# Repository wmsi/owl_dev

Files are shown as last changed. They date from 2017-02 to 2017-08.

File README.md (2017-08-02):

## Welcome to the WMSI Owl Kit Development repository!

Here you can find every sketch ever used on an Owl prototype, as well as some circuit diagrams and files for manufacturing. If you're brand new to the Owls, you'll probably be better off starting with our Comprehensive Owl Guide, which can be found at this link: https://goo.gl/V9kGfm

### examples/
If you are looking for example code for a specific Owl application, <b>check out the examples folder.</b> Most of the names in this folder should be self-explanatory, but if you're confused about a particular application look it up in the guide above.

The code in this folder is by far the best-commented of any in this repository, but once you work through some examples you should be able to navigate the messier prototype code without too many issues.

You can also check out [this guide](https://docs.google.com/document/d/1MRcjBNnCVSWXaH-lBgTyRSfC4LLxEa_yDphGgFJk0CI) on a basic game using the Owls.

### Fritzing/, Eagle/
In the Fritzing and Eagle folders you'll find material related to the Owl circuit as laid out for a breadboard or PCB. The Fritiing files will probably be most useful for reconstructing or understanding how all the parts of the circuit function. Use the Eagle files if you intend to manufacture a PCB or just love staring at circuit diagrams.

### owl projects/
The "owl projects" folder contains sketches for specific educational applications. Each sketch should have a long comment at the top explaining what it was built for and what it does.

### prototype code/
Only go delving into the "prototype code" folder if you have a firm grasp on all the example code. However, if you are struggling with a specific problem, there may be some code in here that solves it :)

However, you may have to peel through layers of old, uncommented, hacked together sketches.

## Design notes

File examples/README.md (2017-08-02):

NOTE: If you are looking for specific school projects such as Profile, more code for Woodland, or our Vermont Teacher workshops, jump up one level in the folder structure and click on "owl projects".

These well-commented examples are meant to serve as a jumping-off point for future Owl projects. They highligt several different directions that the Owls took over the course of development. The files are split into two main folders, for Arduino and Feather (Owl Lite and Owl) support. These folders are meant to be complementary. However, since different use cases were developed on the two different platforms they do not exactly match up. Most significantly, the Arduino folder has greater support for GPS applications since the board naturally interfaces better with GPS and LCD.

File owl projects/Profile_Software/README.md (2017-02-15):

This folder contains firmware for the Owl Prototypes used in Profile's STEAM classroom. 

For our quickstart guide visit goo.gl/jXzwo4.

To change the firmware on your Owl prototype, download this folder from the command line by using the command:

svn checkout https://github.com/wmsi/owl_dev/trunk/Profile_Software

Then you can choose a firmware version (right now only v1 and v2 are operational) and open it with the Arduino IDE. If you do not yet have the Arduino IDE on your computer, you can download it for free from https://www.arduino.cc/en/main/software. Each firmware version contains comments indicating the purpose of each variable and function. For those unfamiliar with programming microcontrollers, a good starting point may be to change the SENDDELAY constant near the top of the .ino file. This changes the wait time in between transmissions and it will be immediately obvious if your intended change took effect. Then you can move on from here to making more ambitious changes in the firmware. If you mess something up beyond repair never fear! The original firmware will remaine on github for you to download over and over again :)

Both Profile Owl Prototypes are currently loaded with profile_v2.ino. This version builds on profile_v1.ino to introduce a faster send rate and real time averaging of incoming signal strength (in receive mode). These changes are meant to help with radio direction finding (RDF) activities. For applications that focus on datalogging or sensor networks profile_v1.ino may still be a better fit. 

Do you have more questions about programming the Owls? Check out our starter guide at goo.gl/jXzwo4 or email mbucchieri@whitemountainscience.org.

Happy tinkering!

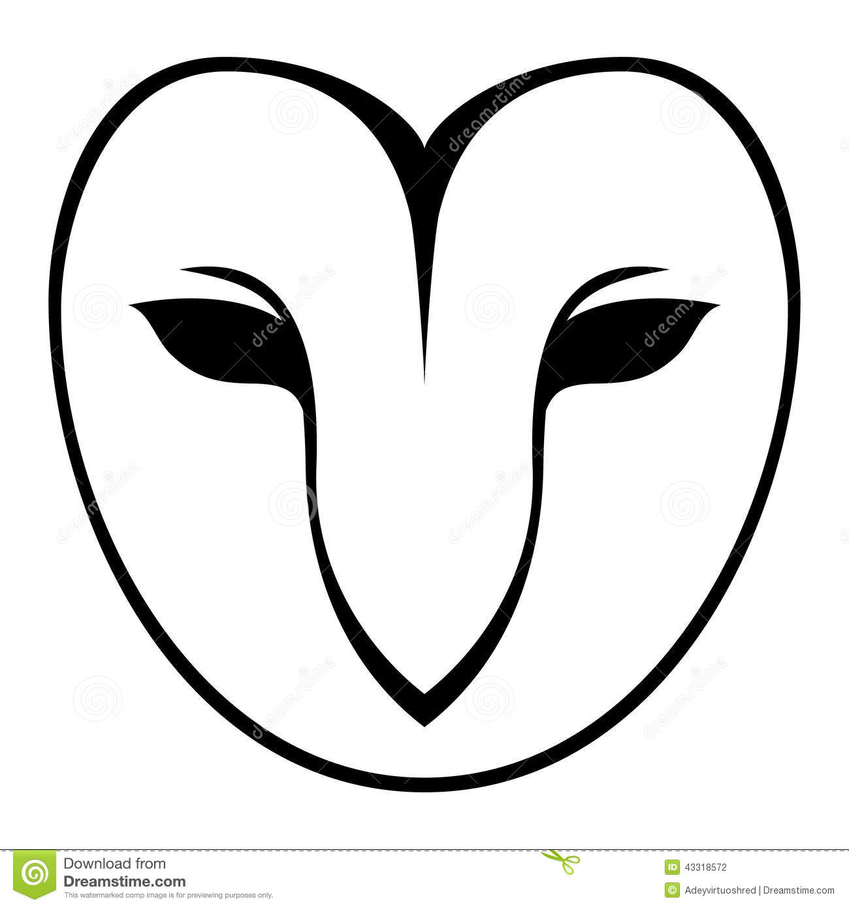
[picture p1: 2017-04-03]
owl projects/Woodland/owl-face-illustration-43318572.jpg

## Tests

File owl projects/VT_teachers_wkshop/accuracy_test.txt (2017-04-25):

LOC:44.280518,-71.691536;TIM:17:31:00;
LOC:44.280525,-71.691521;TIM:17:31:30;
LOC:44.280560,-71.691399;TIM:17:32:01;
LOC:44.280563,-71.691368;TIM:17:32:31;
LOC:44.280575,-71.691307;TIM:17:33:01;
LOC:44.280552,-71.691383;TIM:17:33:32;
LOC:44.280521,-71.691429;TIM:17:34:02;
LOC:44.280540,-71.691360;TIM:17:34:32;
LOC:44.280548,-71.691383;TIM:17:35:03;
LOC:44.280537,-71.691437;TIM:17:35:33;
LOC:44.280525,-71.691452;TIM:17:36:03;
LOC:44.280495,-71.691536;TIM:17:36:34;
LOC:44.280510,-71.691498;TIM:17:37:04;
LOC:44.280563,-71.691345;TIM:17:39:36;
LOC:44.280560,-71.691322;TIM:17:40:06;
LOC:44.280556,-71.691383;TIM:17:40:36;
LOC:44.280563,-71.691353;TIM:17:41:07;
LOC:44.280560,-71.691330;TIM:17:41:37;
LOC:44.280544,-71.691406;TIM:17:42:07;
LOC:44.280552,-71.691452;TIM:17:42:38;
LOC:44.280571,-71.691475;TIM:17:43:08;
LOC:44.280563,-71.691460;TIM:17:43:38;
LOC:44.280567,-71.691475;TIM:17:44:09;
LOC:44.280567,-71.691490;TIM:17:44:39;
LOC:44.280582,-71.691498;TIM:17:45:09;
LOC:44.280582,-71.691475;TIM:17:45:40;
LOC:44.280590,-71.691498;TIM:17:46:10;
LOC:44.280575,-71.691513;TIM:17:46:40;
LOC:44.280548,-71.691528;TIM:17:47:11;
LOC:44.280529,-71.691528;TIM:17:47:41;
LOC:44.280510,-71.691467;TIM:17:48:11;
LOC:44.280502,-71.691406;TIM:17:48:42;
LOC:44.280476,-71.691467;TIM:17:49:12;
LOC:44.280479,-71.691483;TIM:17:49:42;
LOC:44.280468,-71.691505;TIM:17:50:13;
LOC:44.280510,-71.691391;TIM:17:50:43;
LOC:44.280510,-71.691322;TIM:17:51:13;
LOC:44.280407,-71.691566;TIM:17:51:44;
LOC:44.280281,-71.691849;TIM:17:52:14;
LOC:44.280384,-71.691704;TIM:17:52:44;
LOC:44.280563,-71.691345;TIM:17:53:15;
LOC:44.280579,-71.691315;TIM:17:53:45;
LOC:44.280579,-71.691307;TIM:17:54:15;
LOC:44.280563,-71.691353;TIM:17:54:46;
LOC:44.280525,-71.691452;TIM:17:55:16;
LOC:44.280506,-71.691475;TIM:17:55:46;
LOC:44.280495,-71.691505;TIM:17:56:17;
LOC:44.280552,-71.691391;TIM:17:56:47;
LOC:44.280529,-71.691444;TIM:17:57:17;
LOC:44.280529,-71.691414;TIM:17:57:48;
LOC:44.280525,-71.691383;TIM:17:58:18;
LOC:44.280571,-71.691322;TIM:17:58:48;
LOC:44.280548,-71.691345;TIM:17:59:19;
LOC:44.280556,-71.691307;TIM:17:59:49;
LOC:44.280563,-71.691299;TIM:18:00:19;
LOC:44.280563,-71.691345;TIM:18:00:50;
LOC:44.280563,-71.691322;TIM:18:01:20;
LOC:44.280579,-71.691292;TIM:18:01:50;
LOC:44.280586,-71.691231;TIM:18:02:21;
LOC:44.280598,-71.691246;TIM:18:02:51;
LOC:44.280586,-71.691223;TIM:18:03:21;
LOC:44.280552,-71.691490;TIM:18:03:52;
LOC:44.280533,-71.691544;TIM:18:04:22;
LOC:44.280521,-71.691498;TIM:18:04:52;
LOC:44.280533,-71.691544;TIM:18:05:23;
LOC:44.280544,-71.691429;TIM:18:05:53;
LOC:44.280300,-71.691338;TIM:18:06:23;
LOC:44.280502,-71.691200;TIM:18:06:54;
LOC:44.280586,-71.691116;TIM:18:07:24;
LOC:44.280586,-71.691231;TIM:18:07:54;

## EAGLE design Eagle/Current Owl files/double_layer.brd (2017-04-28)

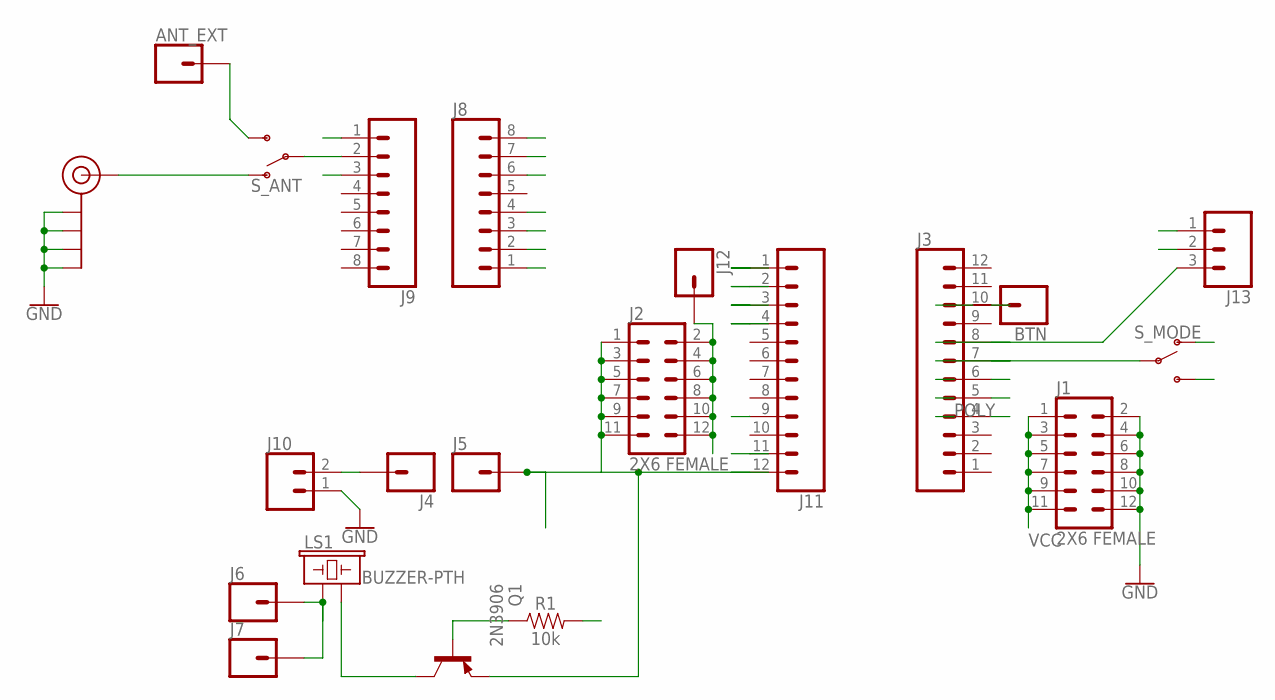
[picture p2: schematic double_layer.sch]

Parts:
ANT_EXT: CONN_01; 1X01
BTN: CONN_01; 1X01
J1, J2: 2X6 FEMALE; 2X6
J3, J11: CONN_12; 1X12
J4, J5, J6, J7, J12: CONN_01; 1X01
J8, J9: CONN_08"; 1X08
J10: CONN_02JST-PTH-2; JST-2-PTH
J13: CONN_03JST-PTH; JST-3-PTH
J$1: SMA_EDGE; SMA-EDGE
LS1: BUZZER-PTH; BUZZER-12MM
Q1: 2N3906; TO92
R1: 10k; AXIAL-0.3
S_ANT: SWITCH-SPDT-PTH-11.6X4.0MM; SWITCH_SPDT_PTH_11.6X4.0MM
S_MODE: SWITCH-SPDT-PTH-11.6X4.0MM; SWITCH_SPDT_PTH_11.6X4.0MM

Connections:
7: J3.7, S_MODE.2
8: J3.8
10: BTN.1, J3.10
ANT: J9.2, S_ANT.2
DIO0: J3.5, J8.6
GND: J1.2, J1.4, J1.6, J1.8, J1.10, J1.12, J2.2, J2.4, J2.6, J2.8, J2.10, J2.12, J3.4, J8.7, J9.1, J9.3, J10.1, J11.11, J12.1, J13.2, J$1.GND@0 (GND), J$1.GND@1 (GND), J$1.GND@2 (GND), J$1.GND@3 (GND), S_MODE.3 (S)
MISO: J8.1, J11.3
MOSI: J8.2, J11.2
unnamed: LS1.- (2), Q1.1 (C)
unnamed: Q1.2 (B), R1.P$1 (1)
unnamed: ANT_EXT.1, S_ANT.3 (S)
unnamed: J$1.SIG (SIGNAL), S_ANT.1 (O)
unnamed: J4.1, J10.2
unnamed: J6.1, J7.1, LS1.+ (1)
NSS: J8.4, J11.1
RAW: J2.1, J2.3, J2.5, J2.7, J2.9, J2.11, J5.1, J11.12, Q1.3 (E)
SCK: J8.3, J11.4
SPKR: J3.6, R1.P$2 (2)
VCC: J1.1, J1.3, J1.5, J1.7, J1.9, J1.11, J8.8, J11.9, J13.1, S_MODE.1 (O)

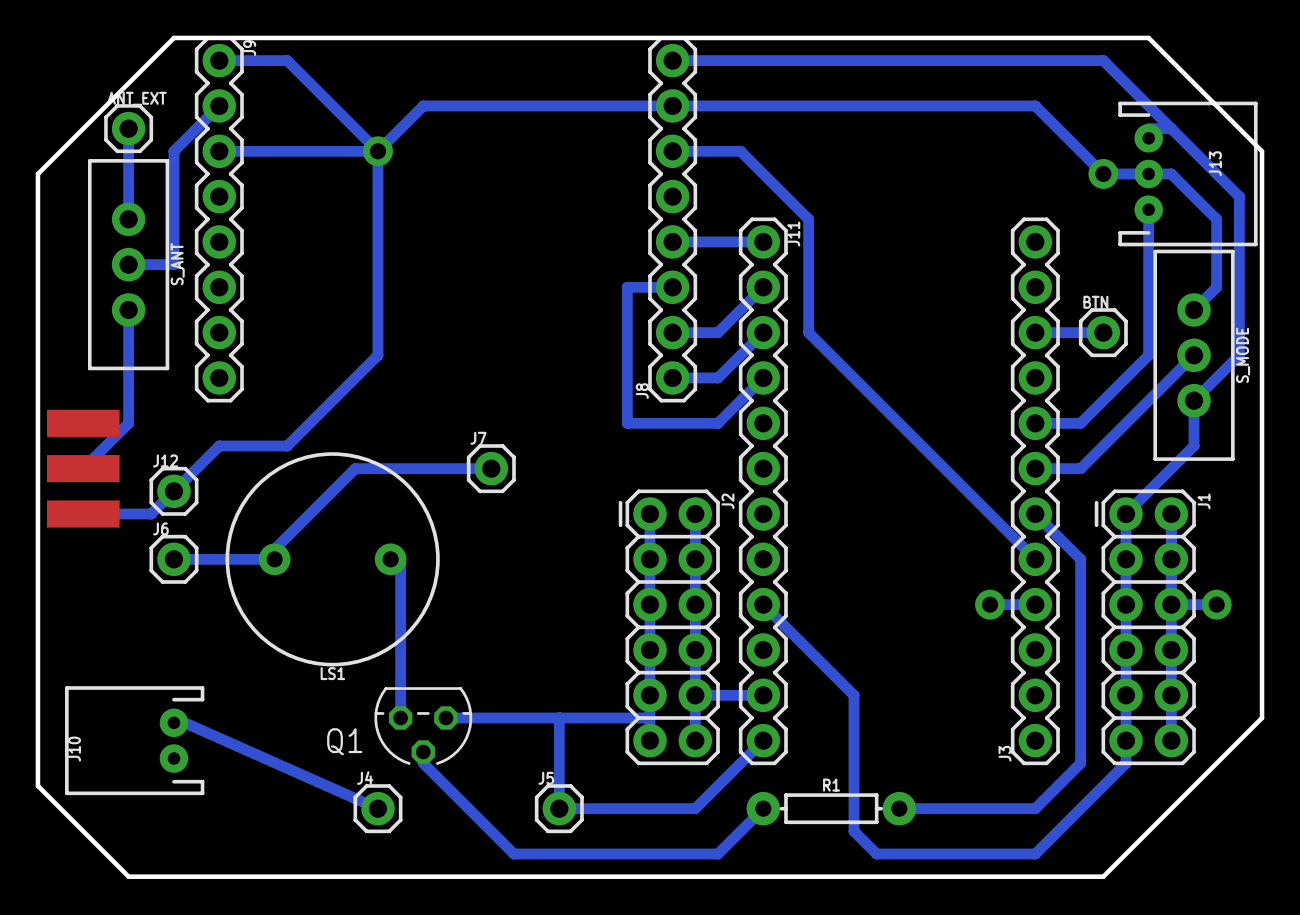
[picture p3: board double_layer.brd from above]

Board: 2 copper layers, 68.6 x 47.0 mm, 21 parts (0 on the bottom side), 18 nets.

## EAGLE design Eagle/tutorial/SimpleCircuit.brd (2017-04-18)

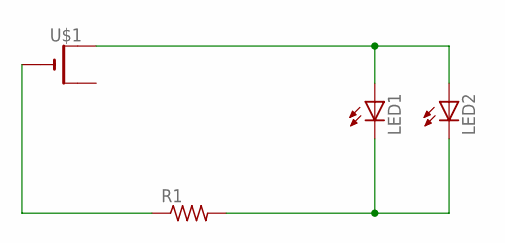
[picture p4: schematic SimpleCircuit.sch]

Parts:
LED1, LED2: LED5MM
R1: R-US_0309/12; 0309/12
U$1: CR2032THM; CR2032-THRU

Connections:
unnamed: LED1.A, LED2.A, U$1.+1 (+)
unnamed: LED1.K (C), LED2.K (C), R1.2
unnamed: R1.1, U$1.-

Board: 2 copper layers, 4 parts (0 on the bottom side), 3 nets, no tracks yet.

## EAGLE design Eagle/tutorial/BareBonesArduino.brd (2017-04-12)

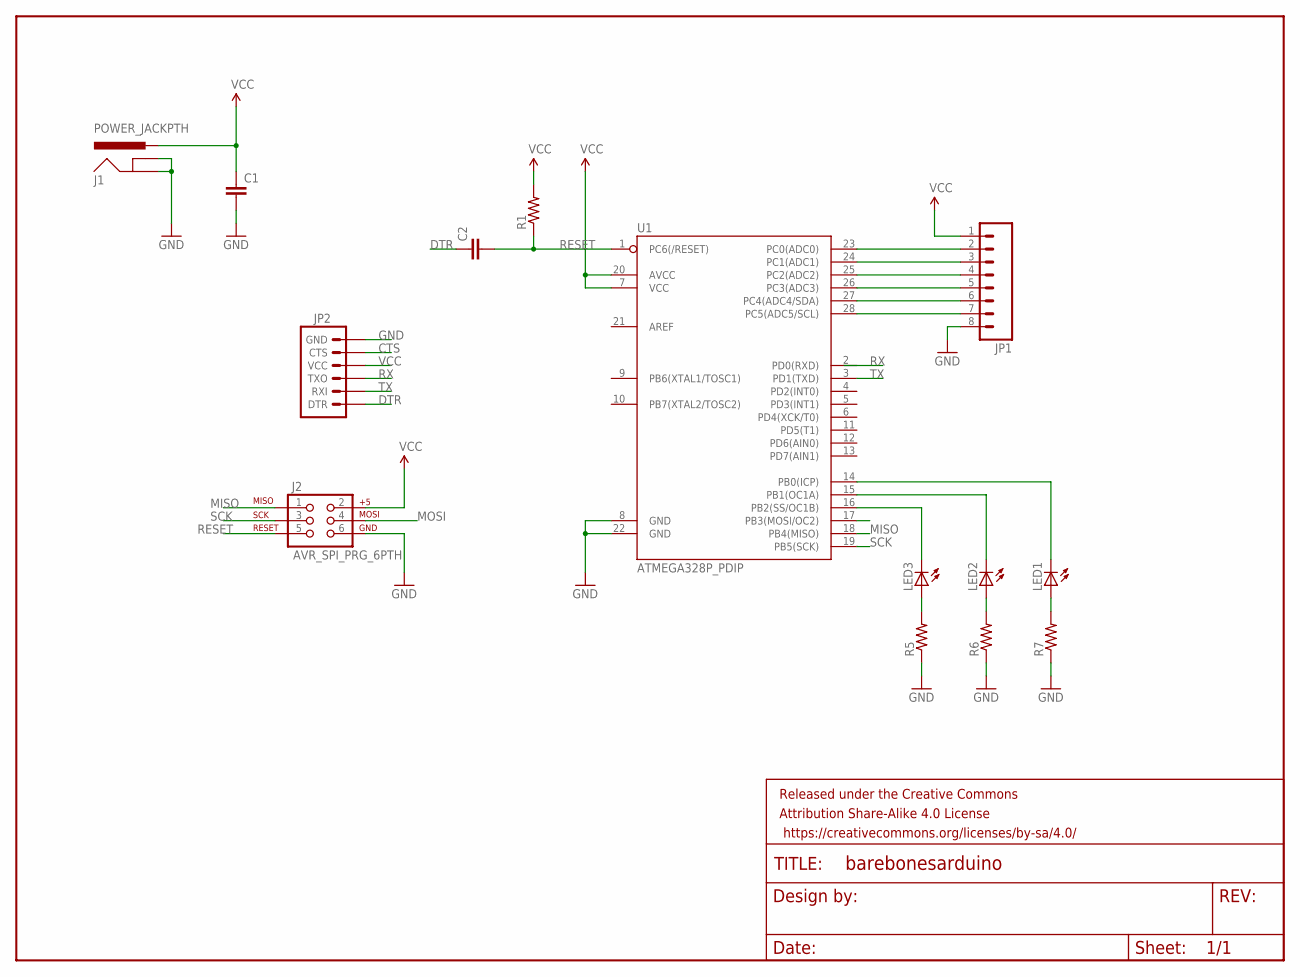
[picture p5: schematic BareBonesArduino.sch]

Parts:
C1, C2: CAPPTH; CAP-PTH-SMALL
FRAME1: FRAME-LETTER; CREATIVE_COMMONS
J1: POWER_JACKPTH; POWER_JACK_PTH
J2: AVR_SPI_PRG_6PTH; 2X3
JP1: M081X08; 1X08
JP2: ARDUINO_SERIAL_PROGRAMPTH; 1X06
LED1, LED2, LED3: LED5MM
R1, R5, R6, R7: RESISTORPTH-1/4W; AXIAL-0.4
U1: ATMEGA328P_PDIP; DIL28-3

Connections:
CTS: JP2.5 (CTS)
DTR: C2.1, JP2.1 (DTR)
GND: C1.2, J1.GND, J1.GNDBREAK, J2.6, JP1.8, JP2.6 (GND), R5.P$1 (1), R6.P$1 (1), R7.P$1 (1), U1.8 (GND), U1.22 (GND)
MISO: J2.1, U1.18 (PB4(MISO))
MOSI: J2.4, LED3.K (C), U1.16 (PB2(SS/OC1B)), U1.17 (PB3(MOSI/OC2))
unnamed: JP1.4, U1.25 (PC2(ADC2))
unnamed: LED2.A, R6.P$2 (2)
unnamed: JP1.2, U1.23 (PC0(ADC0))
unnamed: JP1.3, U1.24 (PC1(ADC1))
unnamed: JP1.5, U1.26 (PC3(ADC3))
unnamed: JP1.7, U1.28 (PC5(ADC5/SCL))
unnamed: JP1.6, U1.27 (PC4(ADC4/SDA))
unnamed: LED2.K (C), U1.15 (PB1(OC1A))
unnamed: LED1.K (C), U1.14 (PB0(ICP))
unnamed: LED3.A, R5.P$2 (2)
unnamed: LED1.A, R7.P$2 (2)
RESET: C2.2, J2.5, R1.P$1 (1), U1.1 (PC6(/RESET))
RX: JP2.3 (TXO)
SCK: J2.3, U1.19 (PB5(SCK))
TX: JP2.2 (RXI), U1.3 (PD1(TXD))
VCC: C1.1, J1.PWR, J2.2, JP1.1, JP2.4 (VCC), R1.P$2 (2), U1.7 (VCC), U1.20 (AVCC)

Board: 2 copper layers, 15 parts (0 on the bottom side), 19 nets, no tracks yet.

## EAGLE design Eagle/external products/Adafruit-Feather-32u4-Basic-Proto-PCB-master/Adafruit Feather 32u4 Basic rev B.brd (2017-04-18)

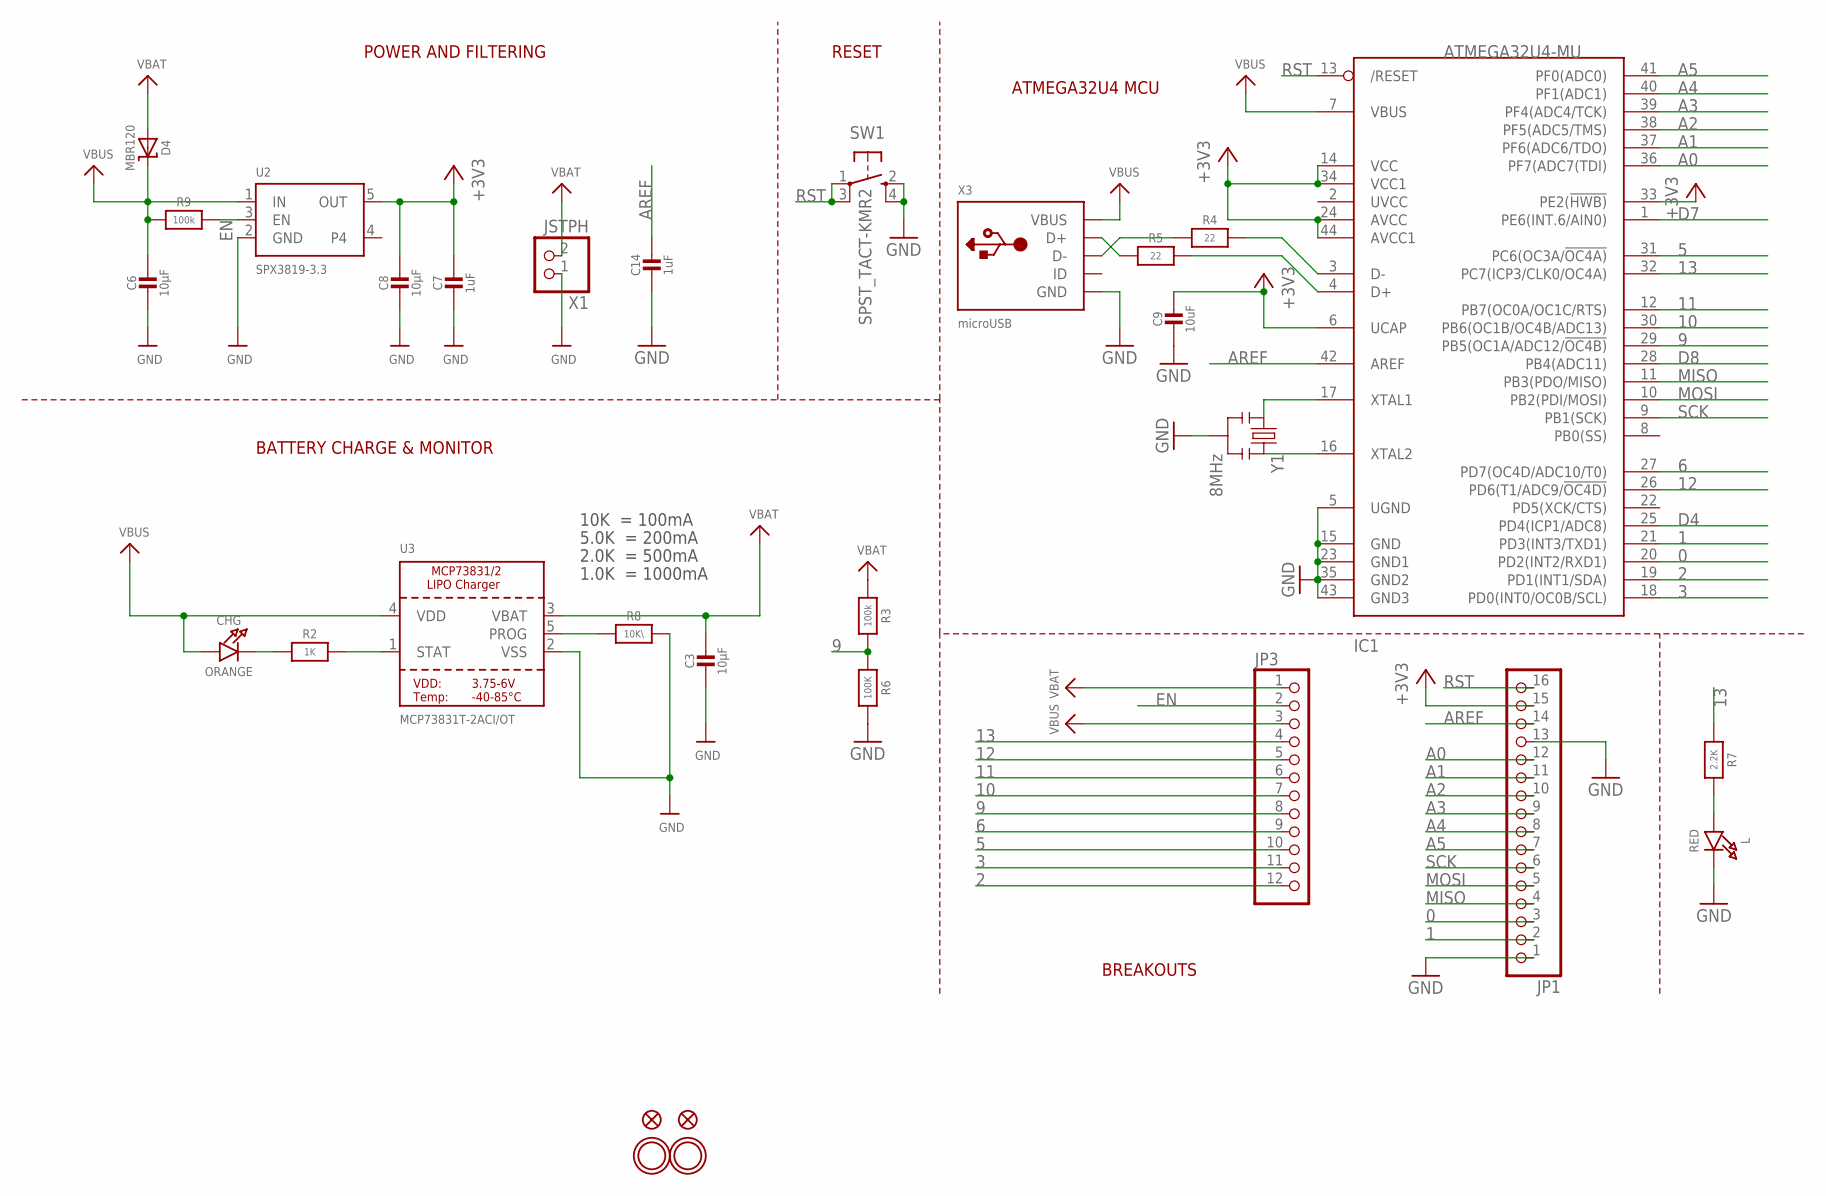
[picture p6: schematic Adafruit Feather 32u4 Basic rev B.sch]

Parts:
C3, C6, C8: 10µF; 0805-NO
C7, C14: 1uF; 0603-NO
C9: 10uF; 0805-NO
CHG: ORANGE; CHIPLED_0805_NOOUTLINE
D4: MBR120; SOD-123
IC1: ATMEGA32U4-MU; TQFN44_7MM
JP1: HEADER-1X16ROUND; 1X16_ROUND
JP3: HEADER-1X12; 1X12_ROUND
L: RED; CHIPLED_0805_NOOUTLINE
R2: 1K; 0603-NO
R3, R9: 100k; 0603-NO
R4, R5: 22; 0603-NO
R6: 100K; _0603MP
R7: 2.2K; 0603-NO
R8: 10K\; 0603-NO
SW1: SPST_TACT-KMR2; KMR2
U2: SPX3819-3.3; SOT23-5
U3: MCP73831T-2ACI/OT; SOT23-5
U$31, U$32: MOUNTINGHOLE2.5; MOUNTINGHOLE_2.5_PLATED
U$34, U$35: FIDUCIAL""; FIDUCIAL_1MM
X1: JSTPH; JSTPH2
X3: microUSB; 4UCONN_20329_V2
Y1: 8MHz; RESONATOR-SMD

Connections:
0: IC1.20 (PD2(INT2/RXD1)), JP1.3
1: IC1.21 (PD3(INT3/TXD1)), JP1.2
2: IC1.19 (PD1(INT1/SDA)), JP3.12
3: IC1.18 (PD0(INT0/OC0B/SCL)), JP3.11
5: IC1.31 (PC6(OC3A/!OC4A)), JP3.10
6: IC1.27 (PD7(OC4D/ADC10/T0)), JP3.9
9: IC1.29 (PB5(OC1A/ADC12/!OC4B)), JP3.8, R3.2, R6.1
10: IC1.30 (PB6(OC1B/OC4B/ADC13)), JP3.7
11: IC1.12 (PB7(OC0A/OC1C/RTS)), JP3.6
12: IC1.26 (PD6(T1/ADC9/!OC4D)), JP3.5
13: IC1.32 (PC7(ICP3/CLK0/OC4A)), JP3.4, R7.1
+3V3: C7.1, C8.1, C9.1, IC1.6 (UCAP), IC1.14 (VCC), IC1.24 (AVCC), IC1.33 (PE2(!HWB)), IC1.34 (VCC1), IC1.44 (AVCC1), JP1.15, U2.5 (OUT)
A0: IC1.36 (PF7(ADC7(TDI)), JP1.12
A1: IC1.37 (PF6(ADC6/TDO)), JP1.11
A2: IC1.38 (PF5(ADC5/TMS)), JP1.10
A3: IC1.39 (PF4(ADC4/TCK)), JP1.9
A4: IC1.40 (PF1(ADC1)), JP1.8
A5: IC1.41 (PF0(ADC0)), JP1.7
AREF: C14.1, IC1.42 (AREF), JP1.14
D4: IC1.25 (PD4(ICP1/ADC8))
D7: IC1.1 (PE6(INT.6/AIN0))
D8: IC1.28 (PB4(ADC11))
D+: IC1.4 (D+), R5.2
D-: IC1.3 (D-), R4.2
EN: JP3.2, R9.2, U2.3 (EN)
GND: C3.2, C6.2, C7.2, C8.2, C9.2, C14.2, IC1.5 (UGND), IC1.15 (GND), IC1.23 (GND1), IC1.35 (GND2), IC1.43 (GND3), JP1.1, JP1.13, L.C, R6.2, R8.2, SW1.2 (S), SW1.4 (S1), U2.2 (GND), U3.2 (VSS), X1.1, X3.BASE@1 (GND), X3.BASE@2 (GND), X3.GND, X3.SPRT@1 (GND), X3.SPRT@2 (GND), X3.SPRT@3 (GND), X3.SPRT@4 (GND), Y1.2
MISO: IC1.11 (PB3(PDO/MISO)), JP1.4
MOSI: IC1.10 (PB2(PDI/MOSI)), JP1.5
unnamed: CHG.C, R2.1
unnamed: L.A, R7.2
unnamed: R2.2, U3.1 (STAT)
unnamed: R8.1, U3.5 (PROG)
unnamed: IC1.16 (XTAL2), Y1.3
unnamed: IC1.17 (XTAL1), Y1.1
unnamed: R5.1, X3.D+
unnamed: R4.1, X3.D-
RST: IC1.13 (/RESET), JP1.16, SW1.1, SW1.3 (P1)
SCK: IC1.9 (PB1(SCK)), JP1.6
VBAT: C3.1, D4.A, JP3.1, R3.1, U3.3 (VBAT), X1.2
VBUS: C6.1, CHG.A, D4.C, IC1.7 (VBUS), JP3.3, R9.1, U2.1 (IN), U3.4 (VDD), X3.VBUS

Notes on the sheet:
POWER AND FILTERING
RESET
ATMEGA32U4 MCU
10K = 100mA
5.0K = 200mA
2.0K = 500mA
1.0K = 1000mA
BATTERY CHARGE & MONITOR
BREAKOUTS

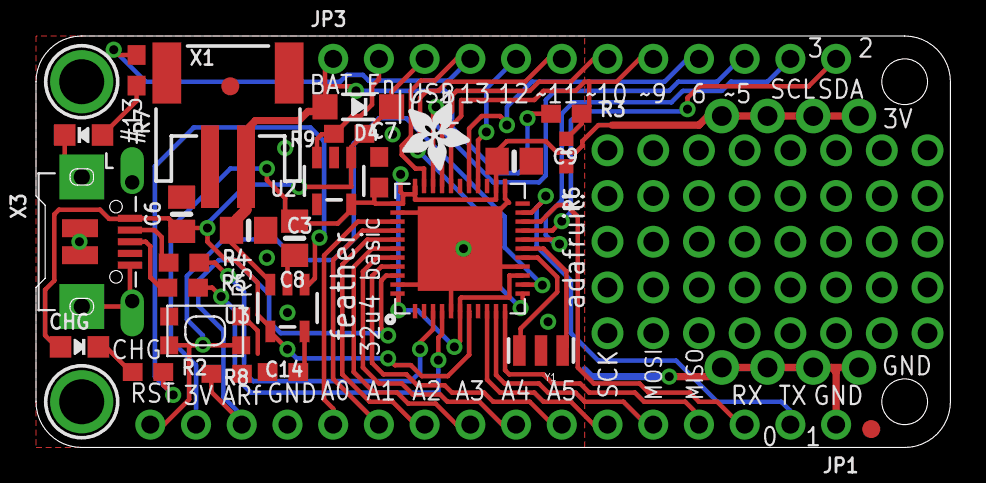
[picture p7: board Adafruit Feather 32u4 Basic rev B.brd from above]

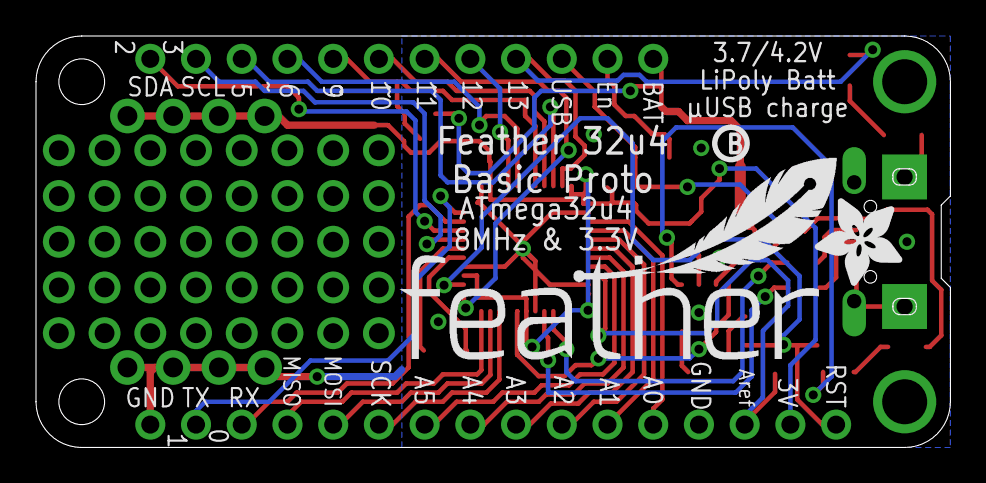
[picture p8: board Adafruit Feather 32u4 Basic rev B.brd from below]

Board: 2 copper layers, 50.8 x 22.9 mm, 34 parts (3 on the bottom side), 37 nets.

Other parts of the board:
U$4: ADAFRUIT_5MM
U$5: FEATHERLOGO
U$6: PCBFEAT-REV-040
U$7: ADAFRUIT_3.5MM

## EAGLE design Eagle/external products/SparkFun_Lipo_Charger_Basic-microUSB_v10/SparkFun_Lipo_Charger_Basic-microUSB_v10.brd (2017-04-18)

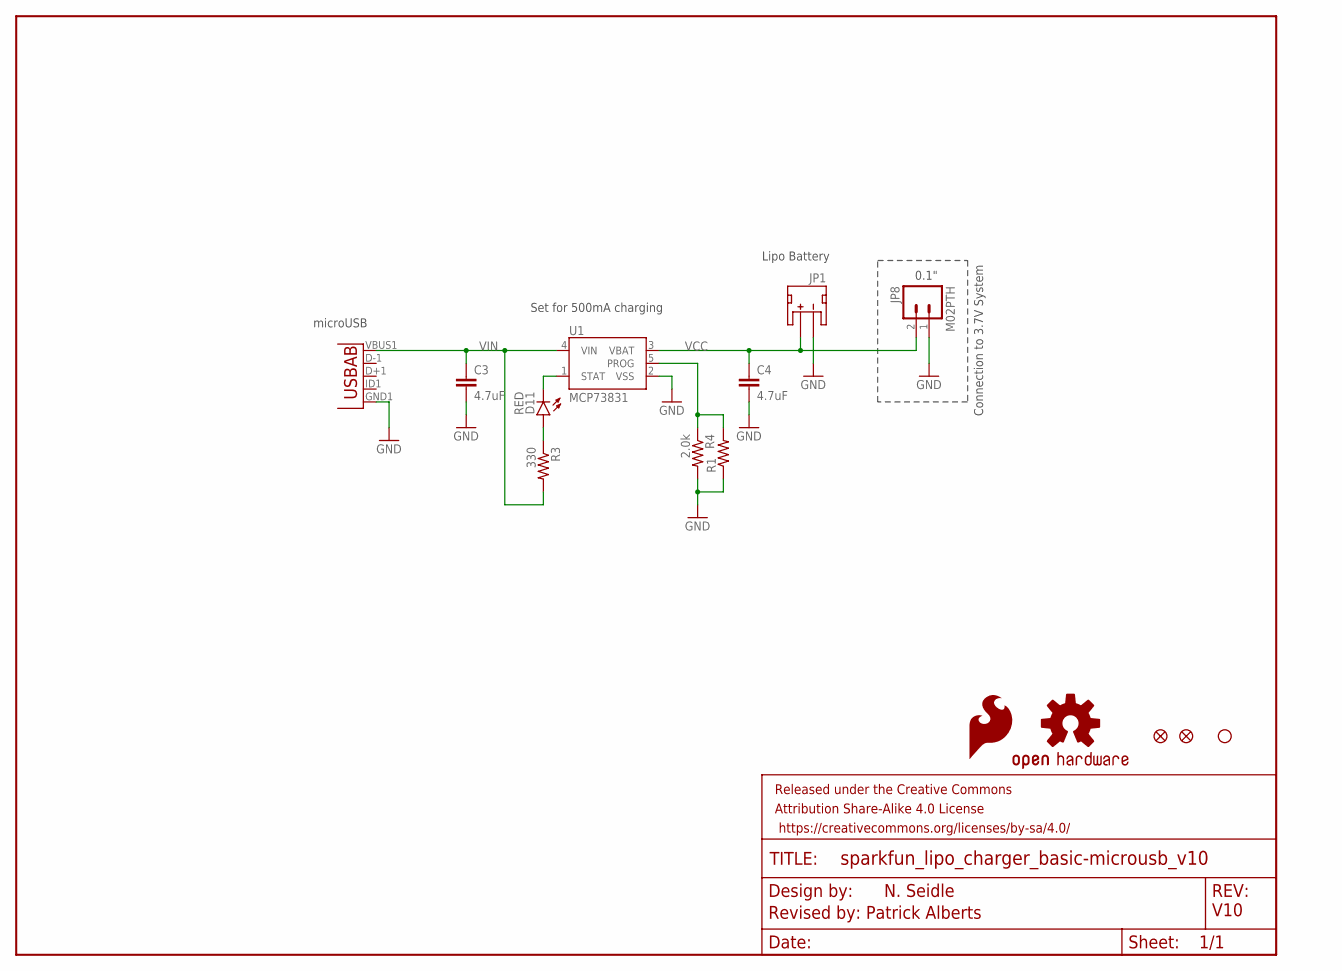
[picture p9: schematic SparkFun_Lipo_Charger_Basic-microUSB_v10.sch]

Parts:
C3, C4: 4.7uF; 0603-CAP
D11: RED; LED-0603
FRAME1: FRAME-LETTER; CREATIVE_COMMONS
JP1: JST; JST-2-SMD
JP2: STAND-OFF
JP3, JP4: FIDUCIAL1X2; FIDUCIAL-1X2
JP8: M02PTH; 1X02
JP9: Micro USB; USB-AB-MICRO-SMD_V03
LOGO1: OSHW-LOGOS; OSHW-LOGO-S
LOGO2: SFE_LOGO_FLAME.1_INCH; SFE_LOGO_FLAME_.1
R1: RESISTORPTH-1/4W-VERT-KIT; AXIAL-0.1EZ
R3: 330; 0603-RES
R4: 2.0k; 0603-RES
U1: MCP73831; SOT23-5

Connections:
GND: C3.2, C4.2, JP1.1 (-), JP8.1, JP9.GND1 (GND), R1.P$1 (1), R4.2, U1.2 (VSS)
unnamed: D11.A, R3.1
PROG: R1.P$2 (2), R4.1, U1.5 (PROG)
STAT: D11.C, U1.1 (STAT)
VCC: C4.1, JP1.2 (+), JP8.2, U1.3 (VBAT)
VIN: C3.1, JP9.VBUS1 (VBUS), R3.2, U1.4 (VIN)

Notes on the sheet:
Set for 500mA charging
Connection to 3.7V System
0.1"
N. Seidle
microUSB
Revised by: Patrick Alberts
V10
Lipo Battery

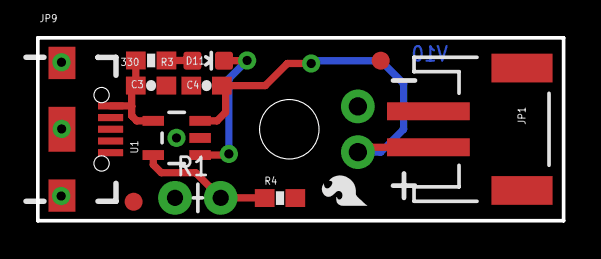
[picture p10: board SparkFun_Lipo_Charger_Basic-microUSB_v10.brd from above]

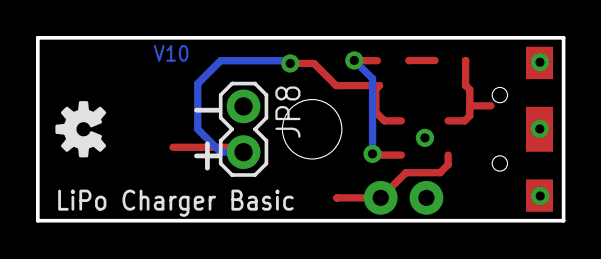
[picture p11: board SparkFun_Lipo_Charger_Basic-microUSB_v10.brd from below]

Board: 2 copper layers, 29.2 x 10.2 mm, 16 parts (2 on the bottom side), 6 nets.

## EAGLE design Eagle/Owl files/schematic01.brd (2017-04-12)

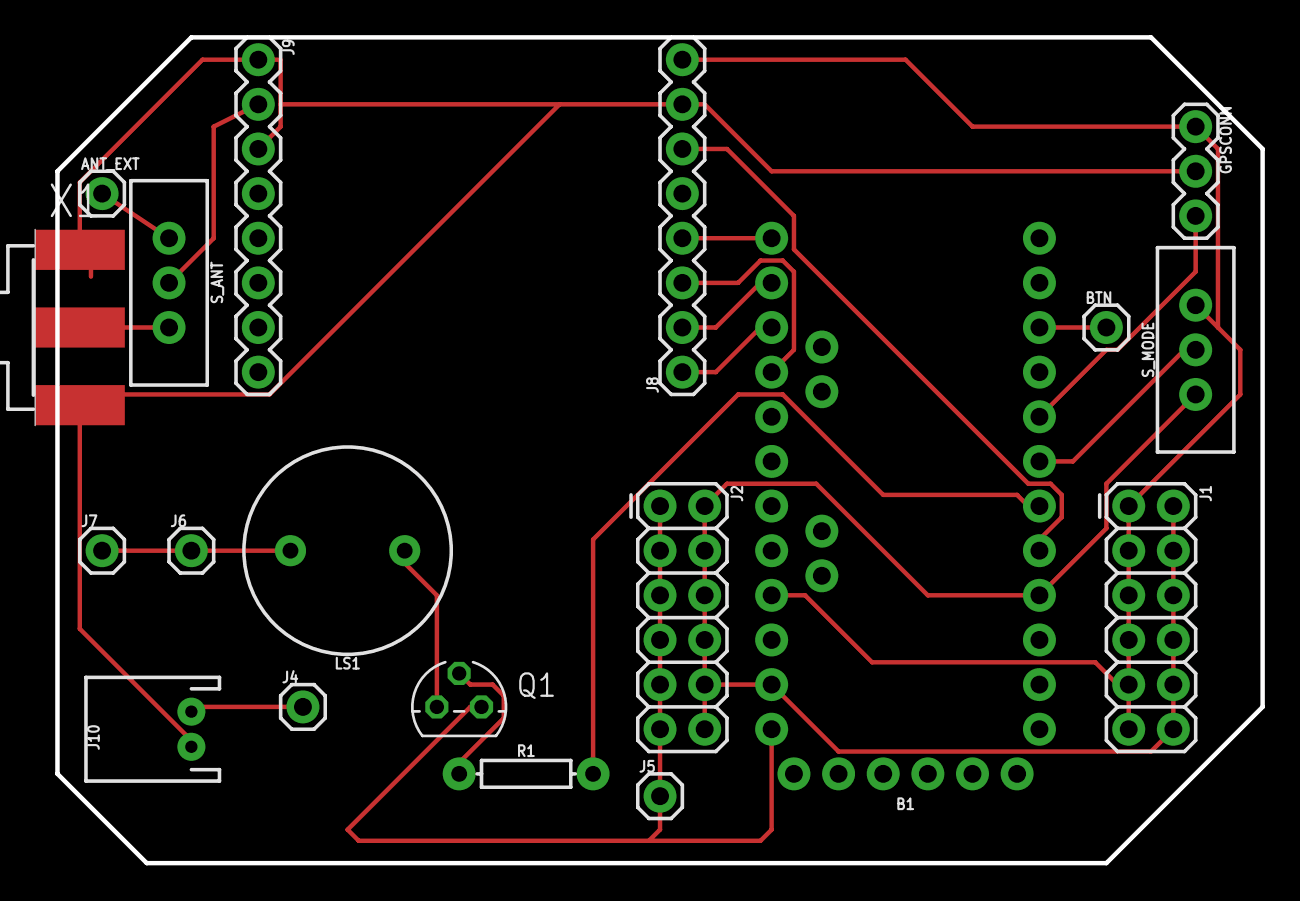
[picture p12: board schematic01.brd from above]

Board: 2 copper layers, 69.8 x 47.0 mm, 20 parts (0 on the bottom side), 19 nets.

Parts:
ANT_EXT: 1X01
B1: ARDUINO_PRO_MINI
BTN: 1X01
FRAME1: FRAME-LETTER; CREATIVE_COMMONS
GPSCONN: 1X03
J1, J2: 2X6 FEMALE; 2X6
J4, J5, J6, J7: 1X01
J8, J9: 1X08
J10: JST-2-PTH
LS1: BUZZER-PTH; BUZZER-12MM
Q1: 2N3906; TO92
R1: 10k; AXIAL-0.3
S_ANT: SWITCH_SPDT_PTH_11.6X4.0MM
S_MODE: SWITCH_SPDT_PTH_11.6X4.0MM
X1: SMA-142-0701-851/861; J502-ND-142-0701-851/861

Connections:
ANT: J9.2, S_ANT.2
DIO0: B1.5, J8.6
MISO: B1.15, J8.1
MOSI: B1.14, J8.2
unnamed: B1.8, GPSCONN.3
unnamed: B1.7, S_MODE.2
unnamed: LS1.-, Q1.3
unnamed: Q1.2, R1.P$1
unnamed: ANT_EXT.1, S_ANT.3
unnamed: S_ANT.1, X1.1
unnamed: B1.10, BTN.1
unnamed: J4.1, J10.2
unnamed: J6.1, J7.1, LS1.+
NSS: B1.13, J8.4
POLY: B1.4, B1.23, GPSCONN.2, J1.2, J1.4, J1.6, J1.8, J1.10, J1.12, J2.2, J2.4, J2.6, J2.8, J2.10, J2.12, J8.7, J9.1, J9.3, J10.1, S_MODE.3, X1.G@1, X1.G@2, X1.G@3, X1.G@4
RAW: B1.24, J2.1, J2.3, J2.5, J2.7, J2.9, J2.11, J5.1, Q1.1
SCK: B1.16, J8.3
SPKR: B1.6, R1.P$2
VCC: B1.21, GPSCONN.1, J1.1, J1.3, J1.5, J1.7, J1.9, J1.11, J8.8, S_MODE.1

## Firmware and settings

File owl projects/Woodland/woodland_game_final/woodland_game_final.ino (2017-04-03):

/*
 * This is the final draft of the Owl program for the Woodland
 * Olders' game. This sketch is intended for the units that 
 * participants will have while playing the game. It handles
 * the GPS Draw station and flippy-flop mini game.
 */

// include libraries for GPS and LCD setup
#include <TinyGPS++.h>
#include <SoftwareSerial.h>

// Include the RFM69 and SPI libraries:
#include <RFM69.h>
#include <SPI.h>

#define GPS     true
#define LCD     true
#define SERIAL  true

// Choose two Arduino pins to use for software serial
// The GPS Shield uses D2 and D3 by default when in DLINE mode
#define GPSRX 5
#define GPSTX 4
#define LCDRX 7
#define LCDTX 6

// button pin
#define BUTTON    7
#define DEBOUNCE  200

// Radio stuff
#define NETWORKID     0   // Must be the same for all nodes
static int MYNODEID;
static int TONODEID;
#define FREQUENCY     RF69_915MHZ
#define TXPOWER       31
#define ENCRYPT       false // Set to "true" to use encryption
#define ENCRYPTKEY    "TOPSECRETPASSWRD" // Use the same 16-byte key on all nodes
#define USEACK        true // Request ACKs or not

#define CENTER        512

// create a softwareSerial object to interface with the LCD
// we can use the same Rx and Tx because GPS only transmits, while LCD only receives

SoftwareSerial lcdSerial(LCDRX,LCDTX); // Rx, Tx
// Create a software serial port called "gpsSerial"
SoftwareSerial gpsSerial(GPSRX, GPSTX);

// The Skytaq EM-506 GPS module included in the GPS Shield Kit
// uses 4800 baud by default
int GPSBaud = 9600;
unsigned long dot_update = 0;
byte num_dots = 1;

// Create a TinyGPS++ object called "gps"
TinyGPSPlus gps;
double my_location[2] = {-71.768792,44.295530};
const int stage_loc[2] = {-71.748118,44.296684};
bool acquired = false;
bool new_write = true;
unsigned long last_event = 0;     // for all-purpose debouncing

const int steps[] = {2,0,1,3,4,3,5,0,1};
const int num_steps = 9;
const String key[] = {"TOP","BOTTOM","LEFT","RIGHT","FRONT","BACK"}; // {+x,-x,+y,-y,+z,-z}
int step_time = 1000;
boolean step_displayed = false;
unsigned long step_start;
int step_index = 0;
bool start_over = true;
int max_mistake_time = 1000;

RFM69 radio;

void setup() {
  // Start the Arduino hardware serial port at 9600 baud
  Serial.begin(9600);

  if(LCD)
    lcdSerial.begin(9600);
    clearLCD();
    
  // Start the software serial port at the GPS's default baud
  gpsSerial.begin(GPSBaud);

  radioSetup();

  pinMode(BUTTON, INPUT_PULLUP);
}

void loop() {
  String send_string;
  String message = "";
  if (radio.receiveDone()) {
    message = printMessage();
  }
  
  // check for GPS update
  while (gpsSerial.available() > 0) {
    if (gps.encode(gpsSerial.read())) {
      myLocation();
    }
  }

  if ((my_location[0] > -71.75 && my_location[0] < -71.745) &&
      (my_location[1] < 44.296 && my_location[1] > 44.293)) {
//if(true) {
    GPSDraw();
  } else if(runFlippyFlop()) {
    flippyFlop();
  }
  
}

//////////////        GPS-related functions         ///////////////////

void myLocation() {
  if(gps.location.isValid()) {
    acquired = true;
    my_location[0] = gps.location.lng();
    my_location[1] = gps.location.lat();
  } else if(LCD) {
    waitScreen();
  }
}

void GPSDraw() {
  String send_string;
  if(acquired) {
    if(new_write && millis() - last_event > step_time) {
      clearLCD();
      writeLine("Press button",1,2);
      writeLine("for new point",2,2);
      new_write = false;
    }
    if(digitalRead(BUTTON) == LOW && millis() - last_event > DEBOUNCE) {
      clearLCD();
      new_write = true;
      last_event = millis();
      writeLine("Sending...",1,3);
      send_string = String(String(my_location[0],5) + "," + String(my_location[1],5));
      radioSend(send_string);
    }
  }
}

int getDistance(long lat_diff, long lng_diff) {
//  Serial.print("differences: "); Serial.print(lat_diff); Serial.print(", "); Serial.println(lng_diff);
  long raw_distance = sqrt(lat_diff*lat_diff + lng_diff*lng_diff);
//  Serial.print("distance: "); Serial.println(raw_distance);
  int distance_m= raw_distance*11;
  return raw_distance;
}

//////////////         flippy flop functions        /////////////////

bool runFlippyFlop() {
  long lng_diff = my_location[0]-stage_loc[0];
  long lat_diff = my_location[1]-stage_loc[1];
  if(getDistance(lat_diff, lng_diff) < 3) {
    clearLCD();
    writeLine("Ready for your",1,1);
    writeLine("next challenge?",2,1);
  }
  unsigned long start_time = millis();
  while(millis() - start_time < 2000) {
    if(digitalRead(BUTTON) == LOW)
      return true;
  }
  return false;
}

void flippyFlop() {
  Serial.println("running flippy flop...");
  bool game_over = false;
  byte orientation;
  while(!game_over) {
    orientation = getOrientation();
//    displayStep();
    if(LCD && !step_displayed)
      writeStep();
    
    if(orientation == steps[step_index]) {
      if(step_start == 0) {
        step_start = millis();
      } else if(millis() - step_start > step_time) {
        Serial.println("got it!");
        step_index++;
        step_start = 0;
        step_displayed = false;
        if(step_index == num_steps) {
          displayDone();
          last_event = 0;
        }
      }
    } else {
      step_start = 0;
      if(step_index != 0 && orientation == steps[step_index-1]) {
        last_event = 0;
      } else if(step_index != 0 && start_over) {
        startOver();   
      }
    }
  }
}

byte getOrientation() {
  int x = analogRead(0);       // read analog input pin 0
  int y = analogRead(1);       // read analog input pin 1
  int z = analogRead(2);       // read analog input pin 2

  int up_reading;
  if(max(x,max(y,z)) - CENTER > CENTER - min(x,min(y,z))) {
    up_reading = max(x,max(y,z));
    if(x == up_reading) {
      return 1;
    } else if(y == up_reading) {
      return 3;
    } else {
      return 5;
    }
  } else {
    up_reading = min(x,min(y,z));
    if(x == up_reading) {
      return 0;
    } else if(y == up_reading) {
      return 2;
    } else {
      return 4;
    }
  }
}

String toCode(String this_step) {
  String temp = "";
  byte code;
  for(int i=0; i<this_step.length(); i++) {
    code = byte(this_step[i])-64;
    temp = String(temp + String(code));
    if(i != this_step.length()-1)
      temp = String(temp + "-");
  }
  return temp;
}

void startOver() {
  if(last_event == 0) {
    last_event = millis();
  } else if(millis() - last_event > max_mistake_time) {
    clearLCD();
    writeLine("Start Over :(",1,2);
    step_index = 0;
    step_displayed = false;
    delay(1500);
    last_event = 0;
  }
}

void writeStep() {
  clearLCD();
//  char temp[16];
  String current_step = toCode(key[steps[step_index]]);
  if(current_step.length() >= 16) {
    String part1 = current_step.substring(0,14);
    String part2 = current_step.substring(14);
    writeLine(part1,1,0);
    writeLine(part2,2,0);
  } else {
    writeLine(current_step,1,0);
  }
  step_displayed = true;
}

void welcomeScreen() {
  clearLCD();
  writeLine("Welcome to",1,3);
  writeLine("Flippy Flop!",2,2);
}

void displayDone() {
  Serial.println("you win!");
  if(LCD) {
    clearLCD();
    writeLine("You Win!",1,4);
    writeLine("Next Number: 9",2,0);
  }
  while(1);
}

//////////////               LCD functions            ///////////////

void waitScreen() {
  if(millis() - dot_update > 1000) {
    num_dots++;
    dot_update = millis();
    if(num_dots == 4)
      num_dots = 1;
  }
  String status = "Acquiring";
  for(int i=0; i<num_dots; i++) {
    status = String(status + ".");
  }
  writeLine(status,1,0);
}

void writeLine(String str, int line, int pos) {
  char temp[16] = "               ";
  int num_chars = str.length();
  lcdSerial.write(254); // move cursor to beginning of first line
  switch(line) {
    case 2:
      lcdSerial.write(191+pos);
    case 1:
      lcdSerial.write(128+pos);
  }
  delay(10);
  for(int i=0; i<num_chars; i++) {
    temp[i] = str[i];
  }
  lcdSerial.write(temp);
}

void clearLCD() {
  lcdSerial.write(254); // move cursor to beginning of first line
  lcdSerial.write(128);

  lcdSerial.write("                "); // clear display
  lcdSerial.write("                ");
}

//////////////               radio functions            ///////////////

void radioSetup() {
  MYNODEID = 1;
  TONODEID = 2;
  
  // Initialize radio
  radio.initialize(FREQUENCY,MYNODEID,NETWORKID);
  radio.setHighPower();    // Only for RFM69HCW & HW!
  radio.setPowerLevel(TXPOWER); // power output ranges from 0 (5dBm) to 31 (20dBm)
  
  // promiscuous mode allows this unit to receive all transmissions on the network
  radio.promiscuous();
  radio.encrypt(ENCRYPTKEY);

}

boolean radioSend(String send_string) {
  boolean ack_recd = false;
  byte send_length = send_string.length();
  static char send_buffer[62];
  for (byte i = 0; i < send_length; i++) {
    send_buffer[i] = send_string[i];
  }

  // There are two ways to send packets. If you want
  // acknowledgements, use sendWithRetry():
  if (USEACK) {
    if (radio.sendWithRetry(TONODEID, send_buffer, send_length, 1)) {
      ack_recd = true;
    }
  } else {
    radio.send(TONODEID, send_buffer, send_length);
  } 
  return ack_recd;
}

String printMessage() {
  char message[radio.DATALEN + 1];
  
  for (byte i = 0; i < radio.DATALEN; i++) {
    message[i] = (char)radio.DATA[i];
  }
  message[radio.DATALEN] = '\0';
  if (radio.ACKRequested()) {
    radio.sendACK();
  }

  return message;
}

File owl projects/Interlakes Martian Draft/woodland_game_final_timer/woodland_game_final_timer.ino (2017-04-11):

/* This software is intended to be run as an eample Owl activity for the 
 *  Woodland school. When powered on, each Owl will start up as either a
 *  transmitter or receiver, depending on the Mode Select switch. In 
 *  receive mode, the Owl searches for waypoints and releases a new compass 
 *  (pointing toward the transmitter) at each waypoint. The transmitter sits
 *  in a central location, broadcasting updates as the timer runs down. When 
 *  found, a button press on the transmitter will notify all receivers that it 
 *  has been retrieved.
 * 
 */

// include libraries for GPS and LCD setup
#include <TinyGPS++.h>
#include <SoftwareSerial.h>

// Include the RFM69 and SPI libraries:
#include <RFM69.h>
#include <SPI.h>

#define LCD     false
#define GPS     false
#define SERIAL  true

// Choose two Arduino pins to use for software serial
// The GPS Shield uses D2 and D3 by default when in DLINE mode
#define GPSRX 5
#define GPSTX 4
#define LCDRX 7
#define LCDTX 6

// create a softwareSerial object to interface with the LCD
// we can use the same Rx and Tx because GPS only transmits, while LCD only receives

// mode select switch
#define MODESELECT    4
#define TRANSMIT      0
#define RECEIVE       1
static bool mode;

// push to beep
#define BLUEWIRE    7
#define REDWIRE     6
#define LOOP        true

const int allotted_time = 25; //minutes
const int broadcast_interval = 540; //seconds
const int s7sTx = 8;
const int s7sRx = 7;
SoftwareSerial s7s(s7sRx, s7sTx);
unsigned long last_update = 0;
unsigned long last_broadcstopast = 0;
boolean flash_state = false;
boolean stop_display = false;
unsigned int stop_time = 0;

#define NETWORKID     0   // Must be the same for all nodes
//#define MYNODEID      1   // My node ID
//#define TONODEID      2   // Destination node ID
static int MYNODEID;
static int TONODEID;

#define FREQUENCY     RF69_915MHZ

// Transmission power (0-31 = 5-20 dBm)
#define TXPOWER       31

// AES encryption (or not):
#define ENCRYPT       false // Set to "true" to use encryption
#define ENCRYPTKEY    "TOPSECRETPASSWRD" // Use the same 16-byte key on all nodes

// Use ACKnowledge when sending messages (or not):
#define USEACK        true // Request ACKs or not

RFM69 radio;

void setup() {
  // Start the Arduino hardware serial port at 9600 baud
  Serial.begin(9600);
  
  s7s.begin(9600);

  clearDisplay();

  pinMode(MODESELECT, INPUT);
  pinMode(BLUEWIRE, INPUT_PULLUP);
  pinMode(REDWIRE, INPUT_PULLUP);

  radioSetup();
}

void loop() {
  String send_string;
  String message = "";
  if (radio.receiveDone()) {
    message = printMessage();
  }
  // update countdown timer
  updateDisplay();

  // broadcast time update
  if((millis()-last_broadcast)/1000 >= broadcast_interval) {
    Serial.println("time udpate");
    broadcastTime();
  }

  if(digitalRead(BLUEWIRE)) {
    radioSend("owl found");
    stop_display = true;
  }
  if(digitalRead(REDWIRE)) {
    fastCount();
  }
}

boolean radioSend(String send_string) {
  boolean ack_recd = false;
  byte send_length = send_string.length();
  static char send_buffer[62];
  for (byte i = 0; i < send_length; i++) {
    send_buffer[i] = send_string[i];
  }
  if (USEACK) {
    if (radio.sendWithRetry(TONODEID, send_buffer, send_length, 1)) {
      ack_recd = true;
    }
  } else {
    radio.send(TONODEID, send_buffer, send_length);
  } 
  return ack_recd;
}

String printMessage() {
  char message[radio.DATALEN + 1];
  for (byte i = 0; i < radio.DATALEN; i++) {
    message[i] = (char)radio.DATA[i];
  }
  message[radio.DATALEN] = '\0';
  if (radio.ACKRequested()) {
    radio.sendACK();
  }

  return message;
}

void updateDisplay() {
  if(millis() - last_update >= 1000) {
    int start_time = allotted_time*60;
    int elapsed_time = millis()/1000;
    int time_remaining = start_time - elapsed_time;
    while(LOOP && time_remaining < 0) {
      time_remaining += 60;
    }
    
    if(stop_display) {
      if(stop_time == 0)
        stop_time = start_time - elapsed_time;
      time_remaining = stop_time;
      flash_state = !flash_state;
    }
    
    unsigned int display_time = max((100*(time_remaining/60) + time_remaining%60),0);
    writeTime(display_time);
  }
}

// count down at double the speed until the blue wire is pulled
void fastCount() {
  int time_remaining = allotted_time*60 - millis()/1000;
  while(time_remaining < 0) {
    time_remaining += 60;
  }
  unsigned long last_write = millis();
  unsigned int display_time;
  while(time_remaining > 0) {
    if(millis() - last_write >= 350) {
      display_time = 100*(time_remaining/60) + time_remaining%60;
      writeTime(display_time);
      time_remaining--;
      last_write = millis();
    }
    if(digitalRead(BLUEWIRE))
      break;
  }
  // flash the last time on the clock forever
  while(1) {
    if(millis() - last_write > 1000) {
      flash_state = !flash_state;
      writeTime(display_time);
      last_write = millis();
    }
  }
}

void writeTime(unsigned int display_time) {
  char tempString[10];
  sprintf(tempString, "%4d", display_time);
  if(display_time < 60)
    tempString[1] = '0';
  if(display_time < 10)
    tempString[2] = '0';
  if(flash_state) {
    for(int i=0;i<4;i++)
      tempString[i] = '-';
  }
  s7s.print(tempString);
  setDecimals(0b00010000);
  last_update = millis();
}

void broadcastTime() {
  String send_string;
  int time_remaining = allotted_time - (millis()/60000);
  if(time_remaining <= 0) 
    send_string = "Out of time!";
  else
    send_string = String(String(time_remaining) + " min. left!");

  // keep trying on future iterations until ack received
  if(radioSend(send_string)) {  
    last_broadcast = millis();
  }
}

// Turn on any, none, or all of the decimals.
//  The six lowest bits in the decimals parameter sets a decimal 
//  (or colon, or apostrophe) on or off. A 1 indicates on, 0 off.
//  [MSB] (X)(X)(Apos)(Colon)(Digit 4)(Digit 3)(Digit2)(Digit1)
void setDecimals(byte decimals) {
  s7s.write(0x77);
  s7s.write(decimals);
}

// Send the clear display command (0x76)
//  This will clear the display and reset the cursor
void clearDisplay() {
  s7s.write(0x76);  // Clear display command
}

void radioSetup() {
  mode = TRANSMIT;
  MYNODEID = 2;
  TONODEID = 1;
  
  // Initialize radio
  radio.initialize(FREQUENCY,MYNODEID,NETWORKID);
  radio.setHighPower();    // Only for RFM69HCW & HW!
  radio.setPowerLevel(TXPOWER); // power output ranges from 0 (5dBm) to 31 (20dBm)
  
  // promiscuous mode allows this unit to receive all transmissions on the network
  radio.promiscuous();
  radio.encrypt(ENCRYPTKEY);

}

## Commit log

2017-01-12 switch mode sketches
    [Untitled.fzz, owl_unit.fzz]
2017-01-19 update for hackandhang:
    [owl_lite_unit.fzz, owl_unit.fzz]
2017-04-03 reorganized code, added examples folder
    [Untitled.fzz, owl_lite_unit.fzz, owl_unit.fzz]
2017-04-07 added sensor_read.ino
2017-04-12 did some reorganizing, added eagle stuff
    [BareBonesArduino.brd, BareBonesArduino.sch, FT232-Breakout.sch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]
2017-04-12 reorganized and added Feather sensor example
2017-04-18 changed folders around
    [Adafruit Feather 32u4 Basic rev B.brd, Adafruit Feather 32u4 Basic rev B.sch, BareBonesArduino.brd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]
2017-04-19 added README
    [owl_lite_unit.fzz, owl_lite_unit_LEDs.fzz]
2017-04-25 updated a readme
    [double_layer.brd, double_layer.sch, lipo_charger.brd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]
2017-04-28 updated eagle files
    [double_layer.brd, double_layer.sch, lipo_charger.brd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]

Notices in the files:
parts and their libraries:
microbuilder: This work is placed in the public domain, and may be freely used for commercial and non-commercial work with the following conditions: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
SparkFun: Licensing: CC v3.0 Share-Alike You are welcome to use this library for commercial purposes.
